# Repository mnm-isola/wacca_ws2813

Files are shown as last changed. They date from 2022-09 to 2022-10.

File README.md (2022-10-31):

# WACCA WS2813 LED PCB Replacement

---

# WARNING: USE AT YOUR OWN RISK

---

## BOM (for use with WS2813E / WS2813B-V4 or below)

| Footprint | Parts | Size | Value  | LCSC | Remark |
| --- | --- | ---- | --- | --- | --- |
| C1-C8 | Decoupling Capacitors  | 0805 | 100nF  | C49678  | |
| C9 | Electrolytic Capacitor | TBD  | 1000uF | TBD | Optional. THT on rev1, SMD on later revisions |
| CN1,CN2 | JST XA 3 pin | | | C265055 | B03B-XASK-1(LF)(SN) |
| CN3 | JST XA 4 pin | | | C264994 | B04B-XASK-1(LF)(SN) |
| D1-D8 | Worldsemi WS2813E | | | C160214 | |
| R1,R2 | | 0805 | 100R | C17408  | |
| U1,U2 | MMBD1503A | | | C242273 | |

---

## BOM (for use with WS2813B-V5)

| Footprint | Parts | Size | Value  | LCSC | Remark |
| --- | --- | ---- | --- | --- | --- |
| C1-C8 | | | | | WS2813B-V5 do not require decoupling caps |
| C9 | Electrolytic Capacitor | TBD  | 1000uF | TBD | Optional. THT on rev1, SMD on later revisions |
| CN1,CN2 | JST XA 3 pin | | | C265055 | B03B-XASK-1(LF)(SN) |
| CN3 | JST XA 4 pin | | | C264994 | B04B-XASK-1(LF)(SN) |
| D1-D8 | Worldsemi WS2813B-V5 | | | C965558 | |
| R1,R2 | | 0805 | 100R | C17408  | |
| U1,U2 | MMBD1503A | | | C242273 | |

## Manufracturing warnings

[Datasheet of WS2813](https://pdf1.alldatasheet.com/datasheet-pdf/view/1134580/WORLDSEMI/WS2813.html)

According to page 7: These LEDs are moisture sensitive, they need to be baked and dried before SMT assembly. Not all PCB fabs have this procedure  (eg JLCPCB's economic option), **be sure to consult and notify the fab of your choice before mass producing the PCBs, otherwise you may end up with extremely high failure rate**. (I learnt it the hard way so you don't have to.)

PCB thickness: 1.6mm

Color: White

---

##### What about a WS2812 clone?

I don't feel like spending time on a inferior design so no.

---

## Licensing

This project is under the [GNU General Public License v3.0](LICENSE.md).

- Commercial use of this project is allowed (i.e. you can go fab these designs and sell them for profit)

- Modifications based on this project needs to be open sourced under the GPLv3 license.

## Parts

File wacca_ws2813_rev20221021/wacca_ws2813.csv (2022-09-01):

Comment | Designator | Footprint | LCSC
100nF | C1,C2,C3,C4,C5,C6,C7,C8 | Capacitor_SMD:C_0805_2012Metric_Pad1.18x1.45mm_HandSolder
1000uF | C9 | Capacitor_THT:CP_Radial_D5.0mm_P2.50mm
JST XA 3p | CN1,CN2 | Connector_JST:JST_XA_B03B-XASK-1_1x03_P2.50mm_Vertical
JST XA 4p | CN3 | Connector_JST:JST_XA_B04B-XASK-1_1x04_P2.50mm_Vertical
WS2813 | D1,D2,D3,D4,D5,D6,D7,D8 | LED_SMD:LED_WS2812_PLCC6_5.0x5.0mm_P1.6mm
M3 | H1,H2 | MountingHole:MountingHole_3.2mm_M3
100 | R1,R2 | Resistor_SMD:R_0805_2012Metric_Pad1.20x1.40mm_HandSolder
1503a | U1,U2 | Package_TO_SOT_SMD:TSOT-23_HandSoldering

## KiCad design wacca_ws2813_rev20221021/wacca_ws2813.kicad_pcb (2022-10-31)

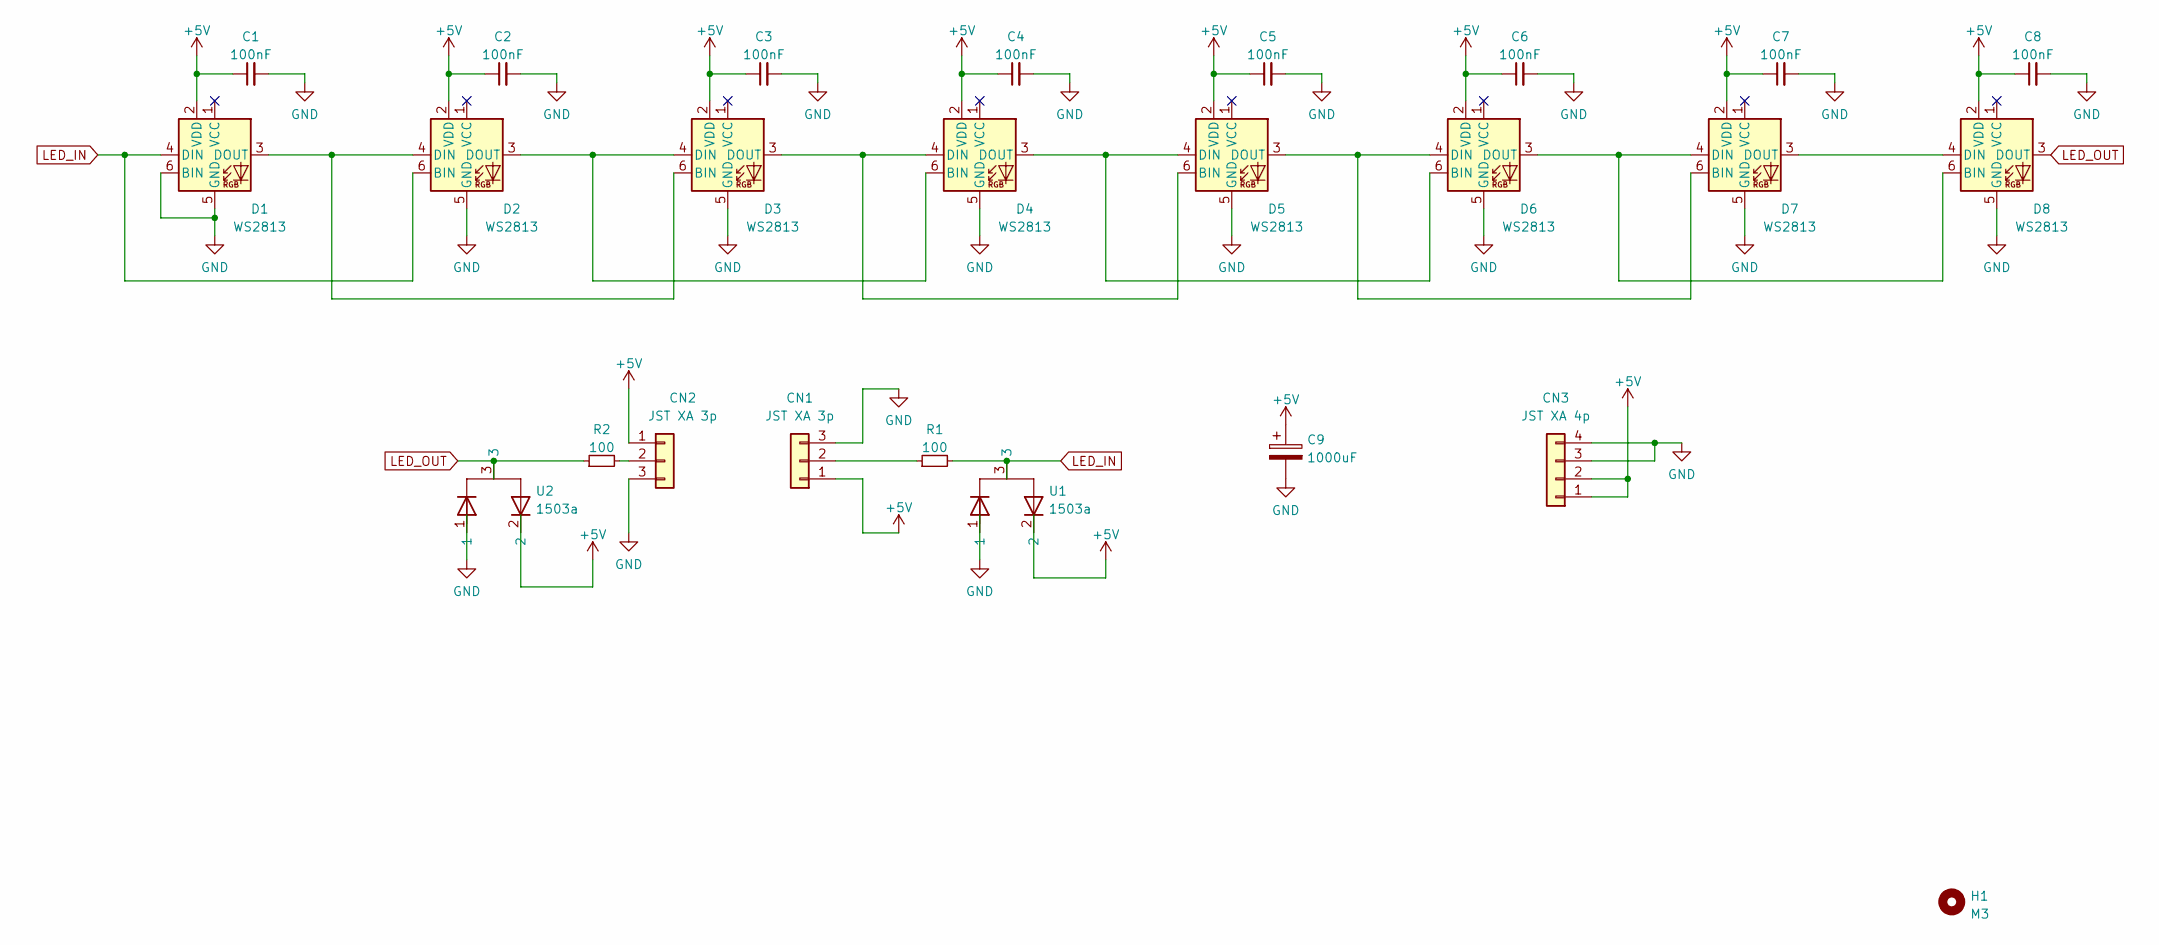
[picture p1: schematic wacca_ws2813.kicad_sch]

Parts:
C1, C2, C3, C4, C5, C6, C7, C8: 100nF; C_0805_2012Metric_Pad1.18x1.45mm_HandSolder
C9: 1000uF; CP_Elec_6.3x5.2
CN1, CN2: JST XA 3p; JST_XA_B03B-XASK-1_1x03_P2.50mm_Vertical
CN3: JST XA 4p; JST_XA_B04B-XASK-1_1x04_P2.50mm_Vertical
D1, D2, D3, D4, D5, D6, D7, D8: WS2813; LED_WS2812_PLCC6_5.0x5.0mm_P1.6mm
H1: M3; MountingHole_3.2mm_M3
R1, R2: 100; R_0805_2012Metric_Pad1.20x1.40mm_HandSolder
U1, U2: 1503a; TSOT-23_HandSoldering

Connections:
+5V: C1.1, C2.1, C3.1, C4.1, C5.1, C6.1, C7.1, C8.1, C9.1, CN1.1, CN2.1, CN3.1, CN3.2, D1.2 (VDD), D2.2 (VDD), D3.2 (VDD), D4.2 (VDD), D5.2 (VDD), D6.2 (VDD), D7.2 (VDD), D8.2 (VDD), U1.2, U2.2
GND: C1.2, C2.2, C3.2, C4.2, C5.2, C6.2, C7.2, C8.2, C9.2, CN1.3, CN2.3, CN3.3, CN3.4, D1.5 (GND), D1.6 (BIN), D2.5 (GND), D3.5 (GND), D4.5 (GND), D5.5 (GND), D6.5 (GND), D7.5 (GND), D8.5 (GND), U1.1, U2.1
LED_IN: D1.4 (DIN), D2.6 (BIN), R1.2, U1.3
LED_OUT: D8.3 (DOUT), R2.1, U2.3
unnamed: CN1.2, R1.1
unnamed: CN2.2, R2.2
unnamed: D1.3 (DOUT), D2.4 (DIN), D3.6 (BIN)
unnamed: D2.3 (DOUT), D3.4 (DIN), D4.6 (BIN)
unnamed: D3.3 (DOUT), D4.4 (DIN), D5.6 (BIN)
unnamed: D4.3 (DOUT), D5.4 (DIN), D6.6 (BIN)
unnamed: D5.3 (DOUT), D6.4 (DIN), D7.6 (BIN)
unnamed: D6.3 (DOUT), D7.4 (DIN), D8.6 (BIN)
unnamed: D7.3 (DOUT), D8.4 (DIN)

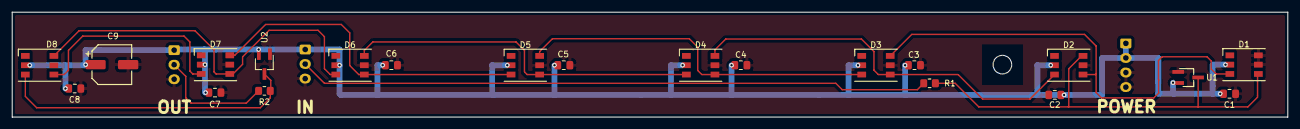
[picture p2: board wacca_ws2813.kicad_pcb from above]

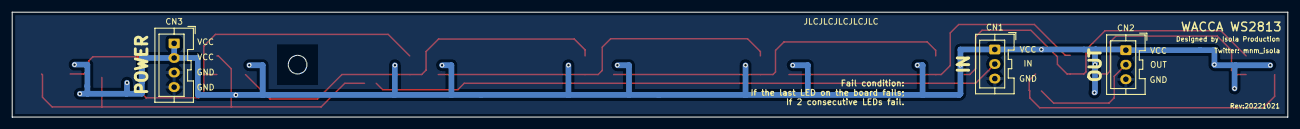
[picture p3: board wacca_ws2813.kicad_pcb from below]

Board: 2 copper layers, 219.0 x 18.0 mm, 25 parts (3 on the bottom side), 13 nets.

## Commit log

2022-09-01 a
    wah
    [wacca_ws2813-B_Cu.gbl, wacca_ws2813-B_Mask.gbs, wacca_ws2813-B_Paste.gbp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]
2022-10-31 added rev20221021
    [wacca_ws2813-B_Cu.gbl, wacca_ws2813-B_Mask.gbs, wacca_ws2813-B_Paste.gbp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]
